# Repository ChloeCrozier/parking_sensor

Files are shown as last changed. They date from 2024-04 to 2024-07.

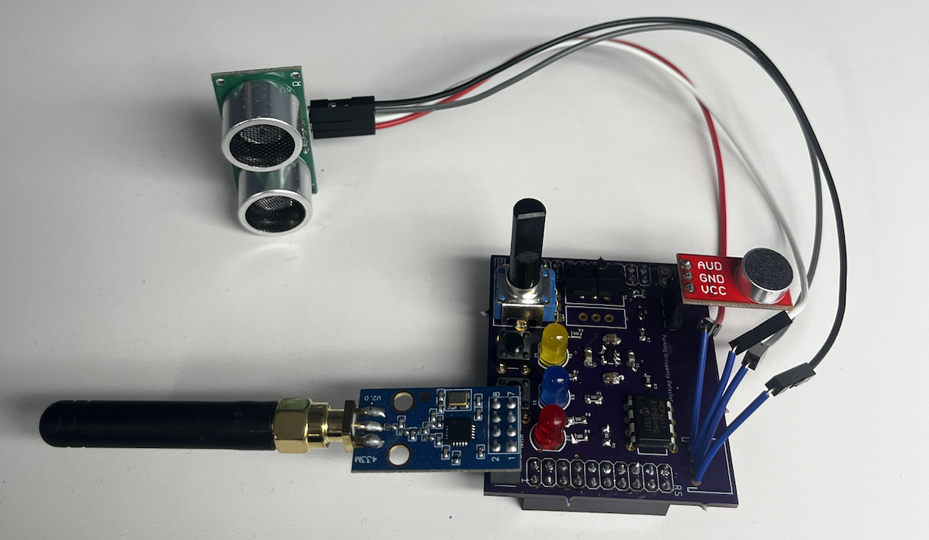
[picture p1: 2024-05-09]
board_schematics/assembled_board.png

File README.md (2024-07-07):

## Embedded Systems Parking Sensor and Occupancy Detection Monitor
Embedded motion sensor that uses an MSB430 Texas Instruments microcontroller to transmit parking space occupancy information.
### Parkshark's Team Members:

- Chloe Crozier | [cscrozi@clemson.edu](mailto:cscrozi@clemson.edu)
- Eliza Sorber | [esorber@clemson.edu](mailto:esorber@clemson.edu)
- Charlie Medlock | [medloc5@clemson.edu](mailto:medloc5@clemson.edu)
- Harrison Langpaul | [hlangpa@clemson.edu](mailto:hlangpa@clemson.edu)

---
<p align="center">
  assembled_board
</p>

- Object Detection with Ultrasound Sensor:
  - The ultrasound sensor detects an object within half of a pre-set 'parking spot' distance.
  - Once the object has been detected for a given number of cycles, it is considered parked.
- LED Status Indication:
  - The LEDs toggle from blue (unoccupied) to red (occupied) to indicate the parking spot status.
- Microphone Polling for Object Departure Detection:
  - After an object is parked, microphone polling is turned on to detect low-frequency noises that suggest the object may be leaving the spot (e.g., engine rumble or footsteps).
- Polling Rate Adjustment with Yellow LED:
  - The ultrasound sensor's polling rate is increased when the yellow LED indicates noise above the set threshold.
- Reverting to Original Polling Rate:
  - When the ultrasound no longer detects an object, microphone polling is turned off, and the ultrasound polling rate is decreased back to the original slow cycle.
- System Controls:
  - There is a button to turn the system on/off.
  - Another button is used to turn debug mode on/off, indicated by LED indicators.
- Potentiometer Path Selection for Filtering:
  - A switch is used to select the potentiometer path when correcting envelope distortions in the microphone filtering.
- Radio Communication for Data Transmission:
  - Radio communication is utilized to transmit information about the status of a parking spot (empty or occupied) and the duration for which an object has been parked.

---

## UNIT TESTING:

### Ultrasound Sensor Testing:

1. Navigate to `ultrasound_testing --> ultrasound_unit_testing` and open the module in Energia (`ultrasound_unit_testing.ino`).
2. Set up a Launchpad with an ultrasound monitor (e.g., a breadboard).
3. Change the `DEBUG_MODE` macro at the top to `true`.
4. Upload the code to your Launchpad.
5. Open the serial monitor to view how many of the tests have passed. These tests validate a valid distance measured, valid measurement based on parking spot size, occupation status, and parking status.

### Radio Testing:

1. For a non-modular version, use the TX/RX examples in the Buffet repository.
2. For a modular design, navigate to `radio_testing --> radio_unit_testing` and open the module in Energia (`radio_unit_testing.ino`).
3. Set up two Launchpads with a CC1101 radio.
4. Set up a TX Launchpad and upload the code with `RECEIVING` and `DEBUG_MODE` set to `false`.
5. Set up a RX Launchpad and upload the code with `RECEIVING` and `DEBUG_MODE` set to `true`.
6. Plug in the transmitting Launchpad after the code starts running on the receiving Launchpad. Verify that the correct number of packets were received, and that the value of the last packet received and the sum of all packets received are accurate.

### Microphone Testing:

1. Navigate to `microphone_unit_testing` and open the module in Energia (`microphone_unit_testing.ino`).
2. Set up a Launchpad with a microphone and upload the code.
3. Set `DEBUG_MODE` to `true` and run the code. The serial monitor will print which tests have passed.
4. For the tests verifying that the LED does/doesn't turn on, manually observe the LED behavior. Ensure that it blinks exactly as expected for each test case. These tests measure the bounds of the microphone thresholds and detect noise above a specified level.

---

## INTEGRATION TESTING:

### Radio Ultrasound Testing:

1. Navigate to `integration_testing --> ultrasound_radio_testing` and open the module in Energia (`ultrasound_radio_testing.ino`).
2. Set up a TX Launchpad with a radio and an ultrasound and upload the code with `RECEIVING` and `DEBUG_MODE` set to `false`.
3. Set up a RX Launchpad with a radio and upload the code with `RECEIVING` and `DEBUG_MODE` set to `true`.
4. Plug in the transmitting Launchpad after the code starts running on the receiving Launchpad. Verify that the correct number of packets are received and that the final parking state is accurately transmitted and calculated from the valid transmitted distances.

### Radio Microphone Ultrasound Testing:

1. Navigate to `integration_testing --> mic_radio_ultrasound_testing` and open the module in Energia (`mic_radio_ultrasound_testing.ino`).
2. Set up a TX Launchpad with a radio and an ultrasound and upload the code with `RECEIVING` and `DEBUG_MODE` set to `false`.
3. Set up a RX Launchpad with a radio and upload the code with `RECEIVING` and `DEBUG_MODE` set to `true`.
4. Plug in the transmitting Launchpad after the code starts running on the receiving Launchpad. Verify that the correct number of packets are received and that the final parking state is accurately transmitted and calculated from the valid transmitted distances. Ensure that the microphone responds to the specified intervals.

---

## FINAL DEMO TESTING:

### Parking Sensor Demo:

1. Navigate to the `parking_sensor_demo` folder and open the module in Energia (`parking_sensor_demo.ino`).

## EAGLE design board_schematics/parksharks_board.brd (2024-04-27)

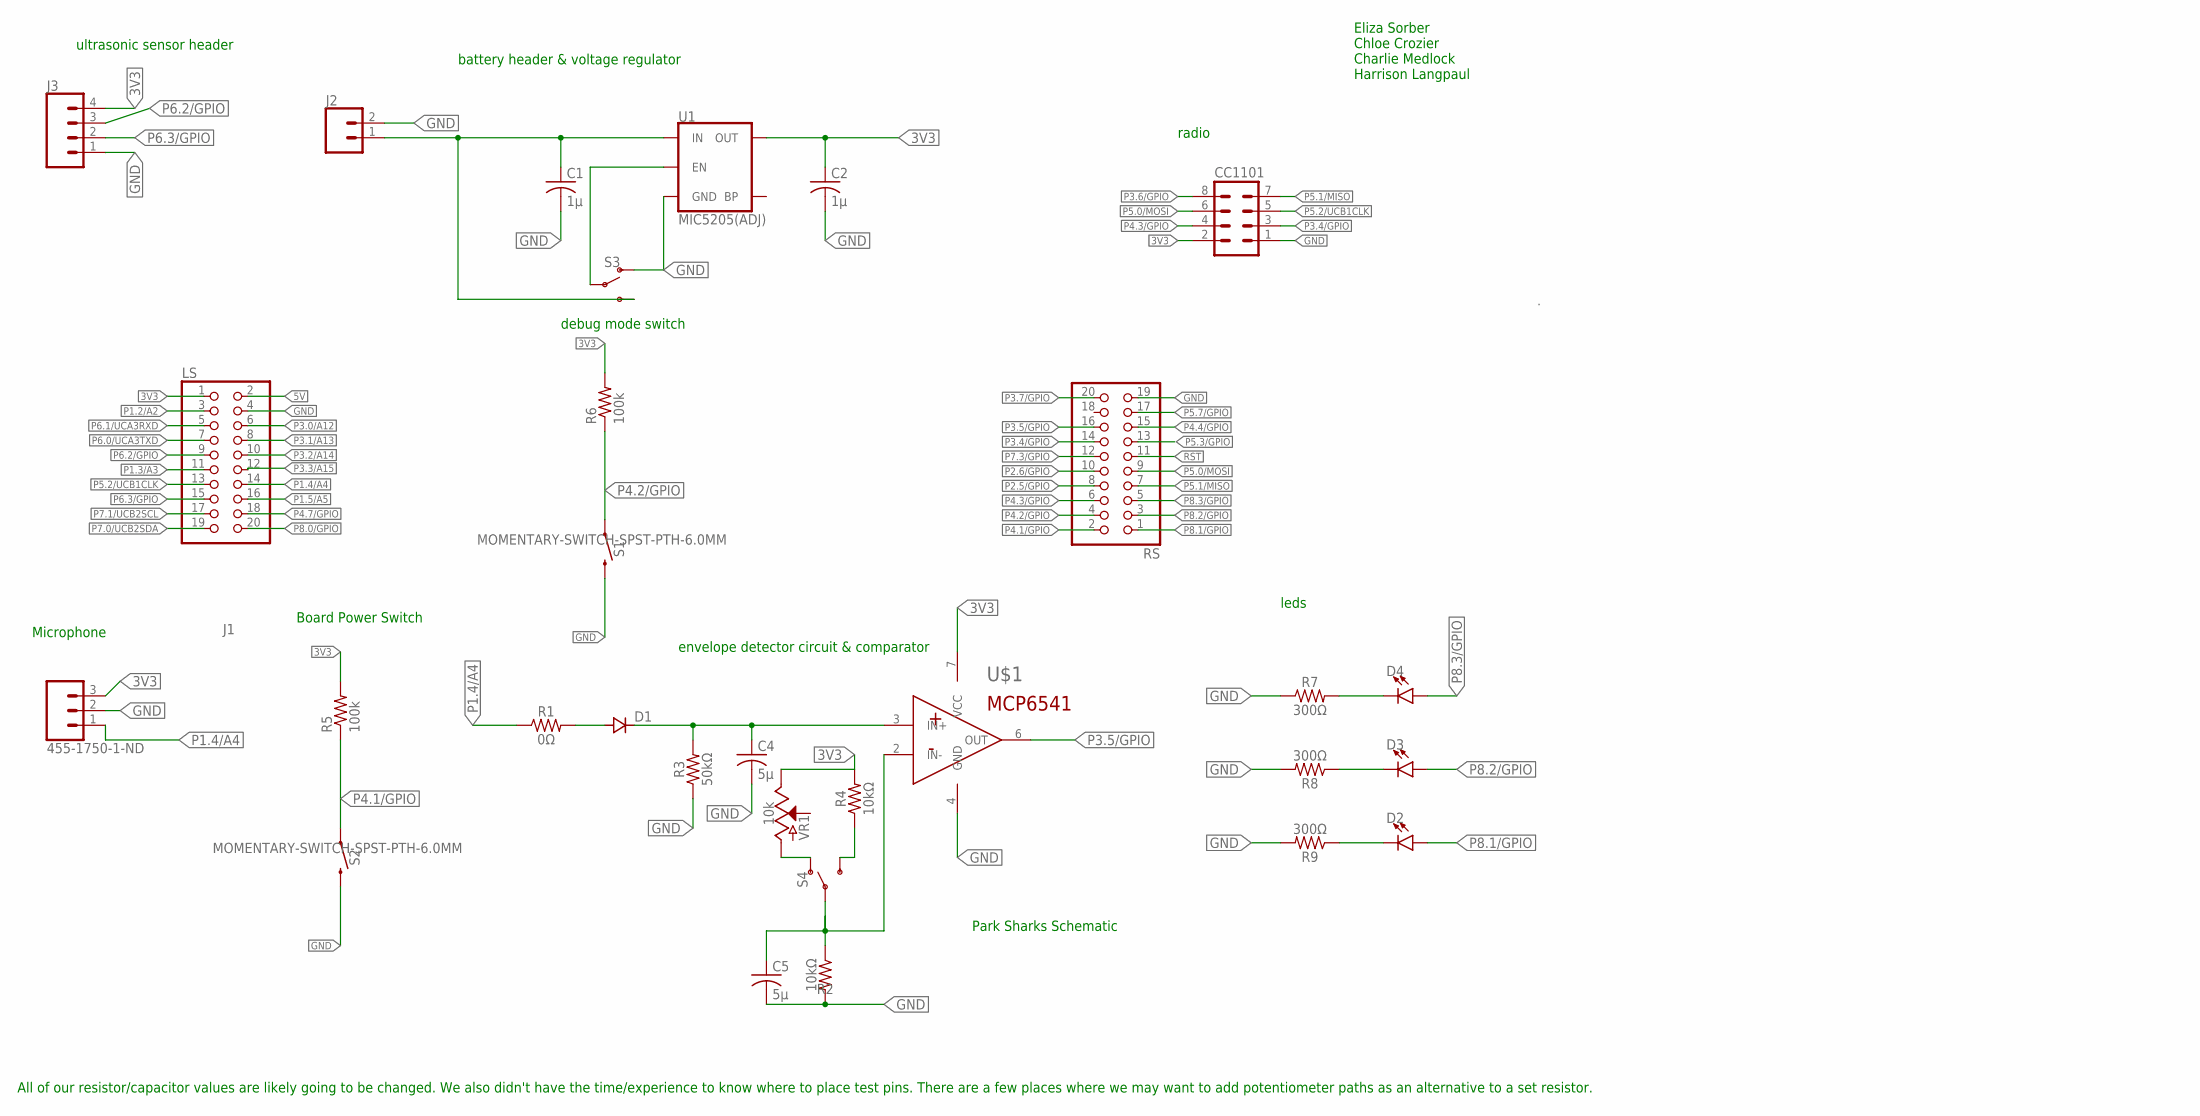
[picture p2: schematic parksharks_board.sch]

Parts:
C1, C2: 1µ; C0805
C4, C5: 5µ; C0805
CC1101: MA04-2
D1: DSOD323; SOD323
D2, D3, D4: LED5MM; LED_5MM
J1: 455-1750-1-ND; 1X03
J2: CONN_02; 1X02
J3: CONN_04JST-PTH; JST-4-PTH
LS: PINHD-2X10; 2X10
R1: 0Ω; 0805
R2, R4: 10kΩ; 0805
R3: 50kΩ; 0805
R5, R6: 100k; R0805
R7, R8, R9: 300Ω; 0805
RS: PINHD-2X10; 2X10
S1, S2: MOMENTARY-SWITCH-SPST-PTH-6.0MM; TACTILE_SWITCH_PTH_6.0MM
S3, S4: SWITCH-SPDT-PTH-11.6X4.0MM; SWITCH_SPDT_PTH_11.6X4.0MM
U1: MIC5205(ADJ); SOT23-5
U$1: MCP654!; DIP08
VR1: 10k; POT-PTH-ALPS

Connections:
3V3: C2.1, CC1101.2, J1.3, J3.4, LS.1, R4.2, R5.2, R6.2, U1.5 (OUT), U$1.7 (VCC), VR1.P$1 (E)
5V: LS.2
GND: C1.2, C2.2, C4.2, C5.2, CC1101.1, J1.2, J2.2, J3.1, LS.4, R2.2, R3.1, R7.1, R8.2, R9.2, RS.19, S1.3 (2), S2.3 (2), S3.1 (O), U1.2 (GND), U$1.4 (GND)
unnamed: D1.2 (A), R1.2
unnamed: C4.1, D1.1 (C), R3.2, U$1.3 (IN+)
unnamed: C5.1, R2.1, S4.2, U$1.2 (IN-)
unnamed: S3.2, U1.3 (EN)
unnamed: S4.1 (O), VR1.P$3 (A)
unnamed: R4.1, S4.3 (S)
unnamed: C1.1, J2.1, S3.3 (S), U1.1 (IN)
unnamed: D4.K (C), R7.2
unnamed: D3.K (C), R8.1
unnamed: D2.K (C), R9.1
P1.2/A2: LS.3
P1.3/A3: LS.11
P1.4/A4: J1.1, LS.14, R1.1
P1.5/A5: LS.16
P2.5/GPIO: RS.8
P2.6/GPIO: RS.10
P3.0/A12: LS.6
P3.1/A13: LS.8
P3.2/A14: LS.10
P3.3/A15: LS.12
P3.4/GPIO: CC1101.3, RS.14
P3.5/GPIO: RS.16, U$1.6 (OUT)
P3.6/GPIO: CC1101.8
P3.7/GPIO: RS.20
P4.1/GPIO: R5.1, RS.2, S2.1
P4.2/GPIO: R6.1, RS.4, S1.1
P4.3/GPIO: CC1101.4, RS.6
P4.4/GPIO: RS.15
P4.7/GPIO: LS.18
P5.0/MOSI: CC1101.6, RS.9
P5.1/MISO: CC1101.7, RS.7
P5.2/UCB1CLK: CC1101.5, LS.13
P5.3/GPIO: RS.13
P5.7/GPIO: RS.17
P6.0/UCA3TXD: LS.7
P6.1/UCA3RXD: LS.5
P6.2/GPIO: J3.3, LS.9
P6.3/GPIO: J3.2, LS.15
P7.0/UCB2SDA: LS.19
P7.1/UCB2SCL: LS.17
P7.3/GPIO: RS.12
P8.0/GPIO: LS.20
P8.1/GPIO: D2.A, RS.1
P8.2/GPIO: D3.A, RS.3
P8.3/GPIO: D4.A, RS.5
RST: RS.11

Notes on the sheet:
Board Power Switch
Microphone
debug mode switch
battery header & voltage regulator
ultrasonic sensor header
radio
envelope detector circuit & comparator
leds
All of our resistor/capacitor values are likely going to be changed. We also didn't have the time/experience to know where to place test pins. There are a few places where we may want to add potentiometer paths as an alternative to a set resistor.
Eliza Sorber Chloe Crozier Charlie Medlock Harrison Langpaul
Park Sharks Schematic

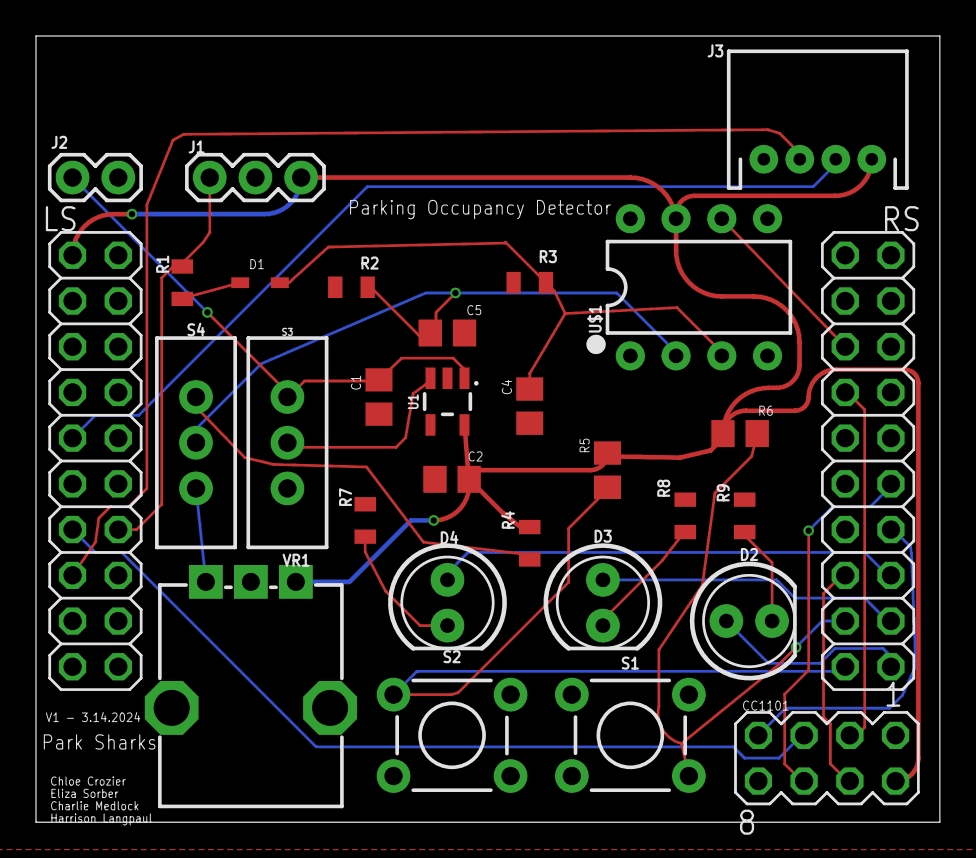
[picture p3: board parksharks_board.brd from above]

Board: 2 copper layers, 50.2 x 43.7 mm, 30 parts (0 on the bottom side), 26 nets.

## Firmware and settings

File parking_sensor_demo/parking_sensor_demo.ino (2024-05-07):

// CPSC 6820 - Team Park Sharks
// 3.25.2024 V0
// Module that will be used for our final prototpye demo

/*
   HEADER FILES
*/
#include <cc1101.h>
#include <macros.h>
#include <pins.h>
#include <registers.h>
// Include the RX and TX header files
#include "radioRX.h"
#include "radioTX.h"
// use the header file we wrote for the ultrasound
#include "ultrasound.h"
// Include the headerfule for the mic module
#include "microphone.h"

/*
   Prototypes
*/

void tickMicrophone(void);
void tickUltrasound(void);
void tickReceiver(void);
void tickTransmitter(void);

/*
   PINS
*/
// Button to control system status (On or Off)
#define ON_OFF_BUTTON P4_2
// Button to control debug status (Toggles LED parking indicator)
#define DEBUG_BUTTON P4_1
//microphone
#define MICROPHONE_PIN P1_4
// Set the trigger pin (we have it connected to P6_2)
#define TRIGGER P6_2
// Set the echo return pin (we have it connected to P6_3)
#define ECHO P6_3
// Envelope detector pin
#define ENVELOPE_PIN P3_5
// LEDs
#define RED_PIN P8_1
#define BLUE_PIN P8_2
#define YELLOW_PIN P8_3


/*
   CONSTANTS
*/
// Set a macro in cm for test verification and also parking spaces are around 5 meters (500 cm)
#define PARKING_SPACE_DIST 100
// Set a macro to determine the minimun number of cycles needer to consider an object occupying the spot as parked
#define PARKING_DETECTION_CYCLES 5
// Radio Channel
#define RADIO_CHANNEL 5
// Radio Data Rate
#define RADIO_DATA_RATE 4

/*
   TIMERS
*/
#define TICK_LENGTH 25
// Interval for running ultrasound check when in slow mode
#define ULTRASOUND_SLOW 1000
// Interval for running ultrasound check when in fast mode
#define ULTRASOUND_FAST 200
// Default length of microphone cycles
#define MICROPHONE_CYCLE 50 // Will sample every cycle
// Default length of microphone cycles
#define RADIO_CYCLE 3500

/*
   OPTIONS
*/
// Set a macro to determine if we are entering receiving (RX) or transmitting (TX) mode
#define RECEIVING_MODE false
// Set a macro for when we want to turn on a unit testing mode
#define DEBUG_MODE true

// Initialize radio objects
RadioRX radioRX;
RadioTX radioTX;

// Define state vars
byte systemRunning = 1;
byte debugMode = DEBUG_MODE;

// Define component objects
Ultrasound ultrasound(TRIGGER, ECHO, PARKING_SPACE_DIST, PARKING_DETECTION_CYCLES);
Microphone microphone(MICROPHONE_PIN, YELLOW_PIN);

// Timers
int timer_m = 0; // Microphone
int timer_u = 0; // Ultrasound
int timer_r = 0; // Radio (Sending)

// Parking state
bool parkedState = false;
// Used to ensure mic was activated for 2 cycles before triggering
bool micState = false;

void setup() {
  Serial.begin(9600);

  // Setup radio
  Radio.Init();
  Radio.SetDataRate(RADIO_DATA_RATE); // Needs to be the same in Tx and Rx
  Radio.SetLogicalChannel(RADIO_CHANNEL); // Needs to be the same as receiver

  // RX setup
  if (RECEIVING_MODE) {
    radioRX.setRX();
    return;
  }

  // Code below should only be run for transmitter (AKA Parking Sensor)
  pinMode(RED_PIN, OUTPUT);
  pinMode(BLUE_PIN, OUTPUT);
  pinMode(YELLOW_PIN, OUTPUT);

  // TX setup
  radioTX.setTX();

  pinMode(ON_OFF_BUTTON, INPUT_PULLUP);
  attachInterrupt(digitalPinToInterrupt(ON_OFF_BUTTON), onOffPress, RISING);
  pinMode(DEBUG_BUTTON, INPUT_PULLUP);
  attachInterrupt(digitalPinToInterrupt(DEBUG_BUTTON), debugPress, RISING);

  //interrupt for envelope detector
  pinMode(ENVELOPE_PIN, INPUT_PULLUP);

  int sensorValue = microphone.readValueDebug(); // Why is this here??
  microphone.triggerDebugLight(sensorValue);

  ultrasound.setCycleLength(ULTRASOUND_FAST);
  microphone.setCycleLength(MICROPHONE_CYCLE);
}

void loop() {
  // RECEIVING mode is for HUB device
  if (RECEIVING_MODE) {
    tickReceiver();
  }

  // Below is all logic for transmitting mode (AKA parking sensor)
  if (!systemRunning) return;

  timer_u += TICK_LENGTH;
  timer_m += TICK_LENGTH;
  timer_r += TICK_LENGTH;

  // Microphone tick
  if (timer_m >= microphone.getCycleLength()) {
    tickMicrophone();
  }

  // Ultrasound tick
  if (timer_u >= ultrasound.getCycleLength()) {
    tickUltrasound();
  }

  // Radio tick
  if (timer_r >= RADIO_CYCLE) {
    tickTransmitter();
  }

  delay(TICK_LENGTH);
}

// tick for RECEIVING_MODE, not based on a timer
void tickReceiver() {
  radioRX.receivePacket();
  if (radioRX.getReceivedStatus()) {
    Serial.print("\n");
    if (debugMode) radioRX.printBuffer();

    int value = radioRX.getPacketVal();
    bool parkingStatus = radioRX.getParkedState();
    Serial.print("The parking sensor has been ");
    Serial.print(parkingStatus ? "occupied" : "available");
    Serial.print(" for ");
    Serial.print(value);
    Serial.print(" seconds.\n");
  }
  return;
}

// Tick Microphone
void tickMicrophone() {
  timer_m %= microphone.getCycleLength();

  int value = debugMode ? microphone.readValueDebug() : microphone.readValue();
  bool micInRange = microphone.valueIsInRange(value);

  // Update LED
  if (debugMode && parkedState && micInRange) {
    digitalWrite(YELLOW_PIN, HIGH);
  } else {
    digitalWrite(YELLOW_PIN, LOW);
  }

  // Update ultrasound tick speed
  if (!micInRange && parkedState) {
    ultrasound.setCycleLength(ULTRASOUND_SLOW);
  } else {
    ultrasound.setCycleLength(ULTRASOUND_FAST);
  }

  micState = micInRange;
}

// Ultrasound Tick
void tickUltrasound() {
  timer_u %= ultrasound.getCycleLength();

  long duration = ultrasound.measureTime();
  long distance = ultrasound.measureDist(duration);

  parkedState = ultrasound.getParkedState();

  // update parked state
  ultrasound.isParked(distance);

  bool newState = ultrasound.getParkedState();

  if (!parkedState && newState) {
    // Car is now parked
    if (debugMode) digitalWrite(RED_PIN, HIGH);
    if (debugMode) digitalWrite(BLUE_PIN, LOW);
    ultrasound.setCycleLength(ULTRASOUND_SLOW);
  } else if (parkedState && !newState) {
    // Car is no longer parked
    if (debugMode) digitalWrite(RED_PIN, LOW);
    if (debugMode) digitalWrite(BLUE_PIN, HIGH);
  }
}

// Radio sending tick
void tickTransmitter() {
  if (debugMode) Serial.println("Radio tick");

  timer_r %= RADIO_CYCLE;
  int parkedTimeInSeconds = (ultrasound.getTimeParked() / 1000);
  // Account for max packet value
  if (parkedTimeInSeconds > 511) parkedTimeInSeconds = 511;
  radioTX.sendData(parkedTimeInSeconds, parkedState);
}

void onOffPress() {
  systemRunning = !systemRunning;
  Serial.print("SYSTEM RUNNING was set to: ");
  Serial.println(systemRunning);
}

void debugPress() {
  debugMode = !debugMode;
  Serial.print("DEBUG MODE was set to: ");
  Serial.println(systemRunning);
}

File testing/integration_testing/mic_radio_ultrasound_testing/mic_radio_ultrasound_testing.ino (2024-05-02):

// Chloe Crozier
// 4.27.2024 V0
// This is a program that functions as an integration test between the ultrasound, microphone, and radio modules
// I heavily used the RX/TX code we used in class to write this program and I directly used my ultrasound, microphone, and radio unit test code
// I changed this code to test that a receiving can get a 10 bit representation of the current measured distance and also the state of whether a object is parked or not
// The microhpone units testts are not fully automated and must be watched in person, but we could always just send the LED h/l values over the radio and verify that way
// CC1101 Datasheet: https://www.ti.com/lit/ds/symlink/cc1101.pdf?ts=1711001249939&ref_url=https%253A%252F%252Fwww.google.com%252F
// Ultrasound Datasheet: https://media.digikey.com/pdf/Data%20Sheets/Adafruit%20PDFs/4019_Web.pdf
// Microphone Datasheet: https://cdn.sparkfun.com/datasheets/Sensors/Sound/CEM-C9745JAD462P2.54R.pdf
//
// Main file to run tests

// These headfiles were used in RX/TX
#include <cc1101.h>
#include <macros.h>
#include <pins.h>
#include <registers.h>
// Include the RX and TX header files
#include "radioRX.h"
#include "radioTX.h"
// use the header file we wrote for the ultrasound
#include "ultrasound.h"
// Include the headerfule for the mic module
#include "microphone.h"
// Included based on custommodule from class
#include "minunit.h"

// Set a macro to determine if we are entering receiving (RX) or transmitting (TX) mode
#define RECEIVING_MODE false
// Set a macro for when we want to turn on a unit testing mode
#define DEBUG_MODE false
// Set the trigger pin (we have it connected to P6_2)
#define TRIGGER P6_2
// Set the echo return pin (we have it connected to P6_3)
#define ECHO P6_3
// Set a macro for the number of packets I want to send in transmitting mode
#define MAX_PACKETS_SENT 10
// Set a macro in cm for test verification and also parking spaces are around 5 meters (500 cm)
#define PARKING_SPACE_DIST 15
// Set a macro to determine the minimun number of cycles needer to consider an object occupying the spot as parked
#define PARKING_DETECTION_CYCLES 5

// Sensitivity for the microphone
#define lowerBound 1000
#define upperBound 3000

// Constant for an unreasonably high microphone value
#define VALUE_TOO_HIGH 100000

#define ledPin P8_2
#define sensorPin P3_5
#include "energia.h"

// Initialize IO objects
RadioRX radioRX;
RadioTX radioTX;
int i;
// From the modular ultrasound_unit_testing code
long duration;
long distance;
Ultrasound ultrasound(TRIGGER, ECHO, PARKING_SPACE_DIST, PARKING_DETECTION_CYCLES);
Microphone mic(sensorPin, ledPin);

void setup() {
  // These lines were in common between both RX and TX's setup functions
  Serial.begin(9600);
  Radio.Init();
  Radio.SetDataRate(4); // Needs to be the same in Tx and Rx
  Radio.SetLogicalChannel(5); // Needs to be the same as receiver
  
  // From the modular microphone_unit_testing code
  mic.setThreshold(lowerBound, upperBound);
  int sensorValue = mic.readValueDebug();
  mic.triggerDebugLight(sensorValue);

  // RX setup
  if(RECEIVING_MODE) {
    radioRX.setRX();
  }
  // TX setup
  else {
    radioTX.setTX();
    // set send index as 1 (the i'th packet is sent with a value of i) for the first packet
    i = 1;
  }
}

//  This test verifies if the parking status bit (index 0 of buffer) accurately detects if the car is parked after sending the last packet
static char *test_parkingStatus() {
  int i = 0;
  int stateCount = 0;
  // I originally did this based on time, but I figured that an infinite loop of it missing a packet can serve as a failed test case
  while(i < MAX_PACKETS_SENT) {
    radioRX.receivePacket();
    if (radioRX.getReceivedStatus()) {
        radioRX.printBuffer();
        radioRX.printPacketInfo();
        Serial.println();
        i++;

        // Count the number of consecutive times the object is occupying the spot
        if(radioRX.getPacketVal() <= (PARKING_SPACE_DIST / 2.0)) {
          stateCount++;
        }
        // Reset the count if it is no longer detected
        else {
          stateCount = 0;
        }
        // Test to see if the radio receives any invalid data
        mu_assert("Error: The value of the last packet received was above the valid ultrasound sensor range", radioRX.getPacketVal() < 450);
        mu_assert("Error: The value of the last packet received was below the valid ultrasound sensor range", (radioRX.getPacketVal() > 2) || (radioRX.getPacketVal() == 0));
    }
  }
  // Ensure that the acutal count matches the expected values
  mu_assert("Error: The number of packets received does not match the number of packets sent", radioRX.getNumPacketsReceived() == MAX_PACKETS_SENT);
  Serial.print("Actual number of packets received ");
  Serial.println(radioRX.getNumPacketsReceived());
  // Ensure that it measured enough values correctly to be able to determine if an object has been occupying the spot long enough to be considered parked
  mu_assert("Error: The final parking state was not calcualted correctly due to invalid values", (stateCount >= PARKING_DETECTION_CYCLES) == radioRX.getParkedState());
  Serial.print("Actual final parking state ");
  Serial.println(stateCount >= PARKING_DETECTION_CYCLES);

  return NULL;
}

// Test to ensure the microphone is reading reasonable values (from mic unit testing code)
static char *test_ensureReasonableBounds() {
  for (int i = 0; i < 100; i++) {
    int level = mic.readValue();
    mu_assert("Error: microphone is reading a zero value.", level != 0);
    mu_assert("Error: microphone is reading an unreasonably high value.", level > VALUE_TOO_HIGH);
    delay(50);
  }

  return NULL;
}

// Test is not automated and must be watched in person, the light should blink EXACTLY 3 times if this test is passed (from mic unit testing code)
static char *test_led_in_range() {
  // Test led range, should blink 3 times
  // Set range to 0-2, then call trigger value of 1, 3 times- LED should blink 3 times
  mic.setThreshold(0, 2);
  for (int i = 0; i < 3; i++) {
    mic.triggerDebugLight(1);
    delay(500);
  }
  
  return NULL;
}


// Test is not automated and must be watched in person, the light should not blink (from mic unit testing code)
// See test above #test_led_in_range, if both are ran then LED should blink exactly 3 times, and no more
static char *test_led_out_of_range() {
    // Test led range, should not blink.
  // Set range to 0-0, then call a trigger value of 1, 3 times
  mic.setThreshold(0, 0);
  for (int i = 0; i < 3; i++) {
    mic.triggerDebugLight(1);
    delay(500);
  }

  return NULL;
}

// This was used in the customemodule example we went over in class
int tests_run = 0;
int tests_passed = 0;
int assertions = 0;
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

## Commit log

2024-04-27 added board and schematic files
    [parksharks_board.brd, parksharks_board.sch]
2024-05-09 added board picture

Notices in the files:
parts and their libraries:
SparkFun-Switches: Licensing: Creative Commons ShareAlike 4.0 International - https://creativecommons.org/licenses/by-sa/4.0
